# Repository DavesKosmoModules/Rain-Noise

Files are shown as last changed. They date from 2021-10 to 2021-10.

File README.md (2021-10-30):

# Rain-Noise

Rain Photo

25mm Noise Generator

- Noise generator
- White
- Pink
- Red / Brown
- Violet

Contained are schematics & gerber files for pcb fabrication of both electrical and front panel. This is sutiable for entry level however a basic level of electronics, soldering, fault finding, and some basic tools are required.

[Schematic](/Docs/Rain-Schematic.pdf)

[BOM](Docs/Rain-BOM.pdf)

To calibrate, four pots can be accessed through the holes on the front plate. 

 ` ` | ` `
 --| --
` `   | PINK      
WHITE| 
BROWN   | VIOLET

- Adjust the white pot first as this noise if filtered for the remaining sources, looking for an output of +- 5V. 
- Adjust the three remaining pots for the respective output levels. 

If you wish to edit in ki-cad the following dependencies are required

 https://github.com/holmesrichards/Kosmo_panel
 
 https://github.com/holmesrichards/aoKicad

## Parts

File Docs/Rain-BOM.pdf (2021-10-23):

Id | Designator | Package | Quantity | Designation
| 1 J2,J1,J3,J5 | Jack_6.35mm_PJ_629HAN | | 4 AudioJack2_SwitchT
2 C1,C3,C4,C10 C_Disc_D3.0mm_W1.6mm_P2.50mm | 4 1uF
| 3 c1,C17,C18 | CP_Radial_D6.3mm_P2.50mm | | 3 10uF
| 4 C2 | C_Disc_D3.0mm_W1.6mm_P2.50mm | | 1 3.3nF
| 5 C5 | C_Disc_D3.0mm_W1.6mm_P2.50mm | | 1 220nF
| 6 C6,C7,C8 | C_Disc_D3.0mm_W1.6mm_P2.50mm | | 3 47nF
| 7 C9 | C_Disc_D3.0mm_W1.6mm_P2.50mm | | 1 33nF

8

| C21,C22,C23,C
| 24 | C_Disc_D3.0mm_W1.6mm_P2.50mm | | 4 0.1uF
| 9 D1,D2 | D_DO‐41_SOD81_P10.16mm_Horizontal | | 2 1N5817
| 10 J6 | Power_Header | | 1 Synth_power_2x5_passive
| 11 Q1 | TO‐92_Inline_Wide | | 1 2N3904
| 12 R1,R2,R8 | R_Axial_DIN0207_L6.3mm_D2.5mm_P10.16mm_Horizontal | | 3 470k
| 13 R3 | R_Axial_DIN0207_L6.3mm_D2.5mm_P10.16mm_Horizontal | | 1 6k8

14

R4,R6,R9,R12,R
13,R14,R15,R1
6 | R_Axial_DIN0207_L6.3mm_D2.5mm_P10.16mm_Horizontal | 8 10k
15 R5 | R_Axial_DIN0207_L6.3mm_D2.5mm_P10.16mm_Horizontal | 1 3k

16

R7,R22,R23,R2
4,R26 | R_Axial_DIN0207_L6.3mm_D2.5mm_P10.16mm_Horizontal | 5 1k
17 R10 | R_Axial_DIN0207_L6.3mm_D2.5mm_P10.16mm_Horizontal | 1 300
18 R11 | R_Axial_DIN0207_L6.3mm_D2.5mm_P10.16mm_Horizontal | 1 2.2M

19

RV1,RV2,RV3,R
V4 | Potentiometer_Bourns_3296W_Vertical_screw_centered | 4 1M
20 U1,U2 | DIP‐14_W7.62mm_Socket_LongPads | 2 TL074

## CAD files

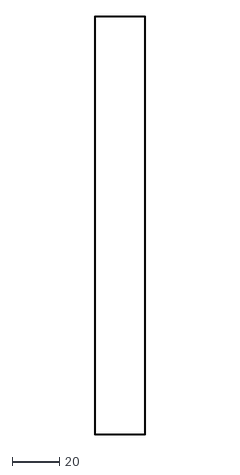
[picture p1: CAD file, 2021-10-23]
dxf/Kosmo Noise-Edge_Cuts.dxf
21.2 x 176.2

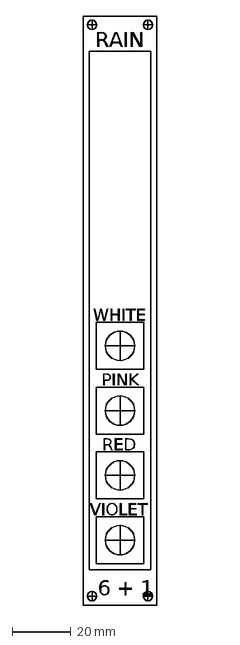
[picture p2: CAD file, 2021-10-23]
NoisePlatesExport.dxf
6 + 1
RAIN
PINK
WHITE
RED
VIOLET

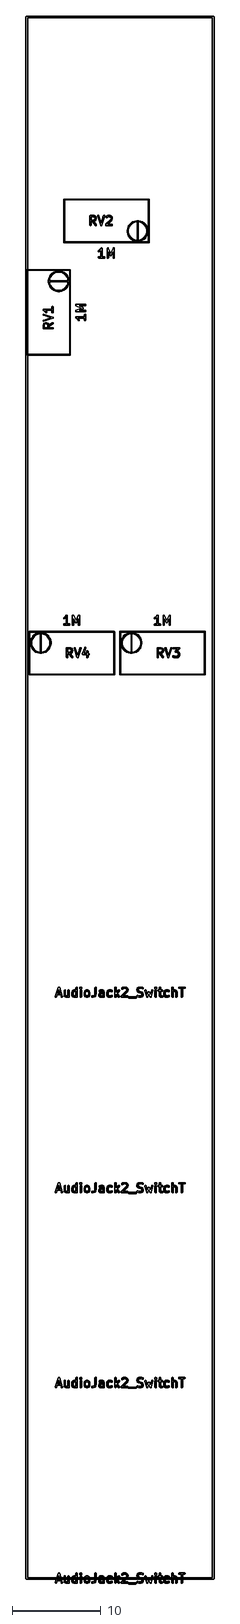
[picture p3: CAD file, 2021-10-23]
dxf/Kosmo Noise-F_Fab.dxf
21.2 x 176.7

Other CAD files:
Noise Faceplates.dwg
NoisePlatesExport.dwg
dxf/Kosmo Noise-F_SilkS.dxf

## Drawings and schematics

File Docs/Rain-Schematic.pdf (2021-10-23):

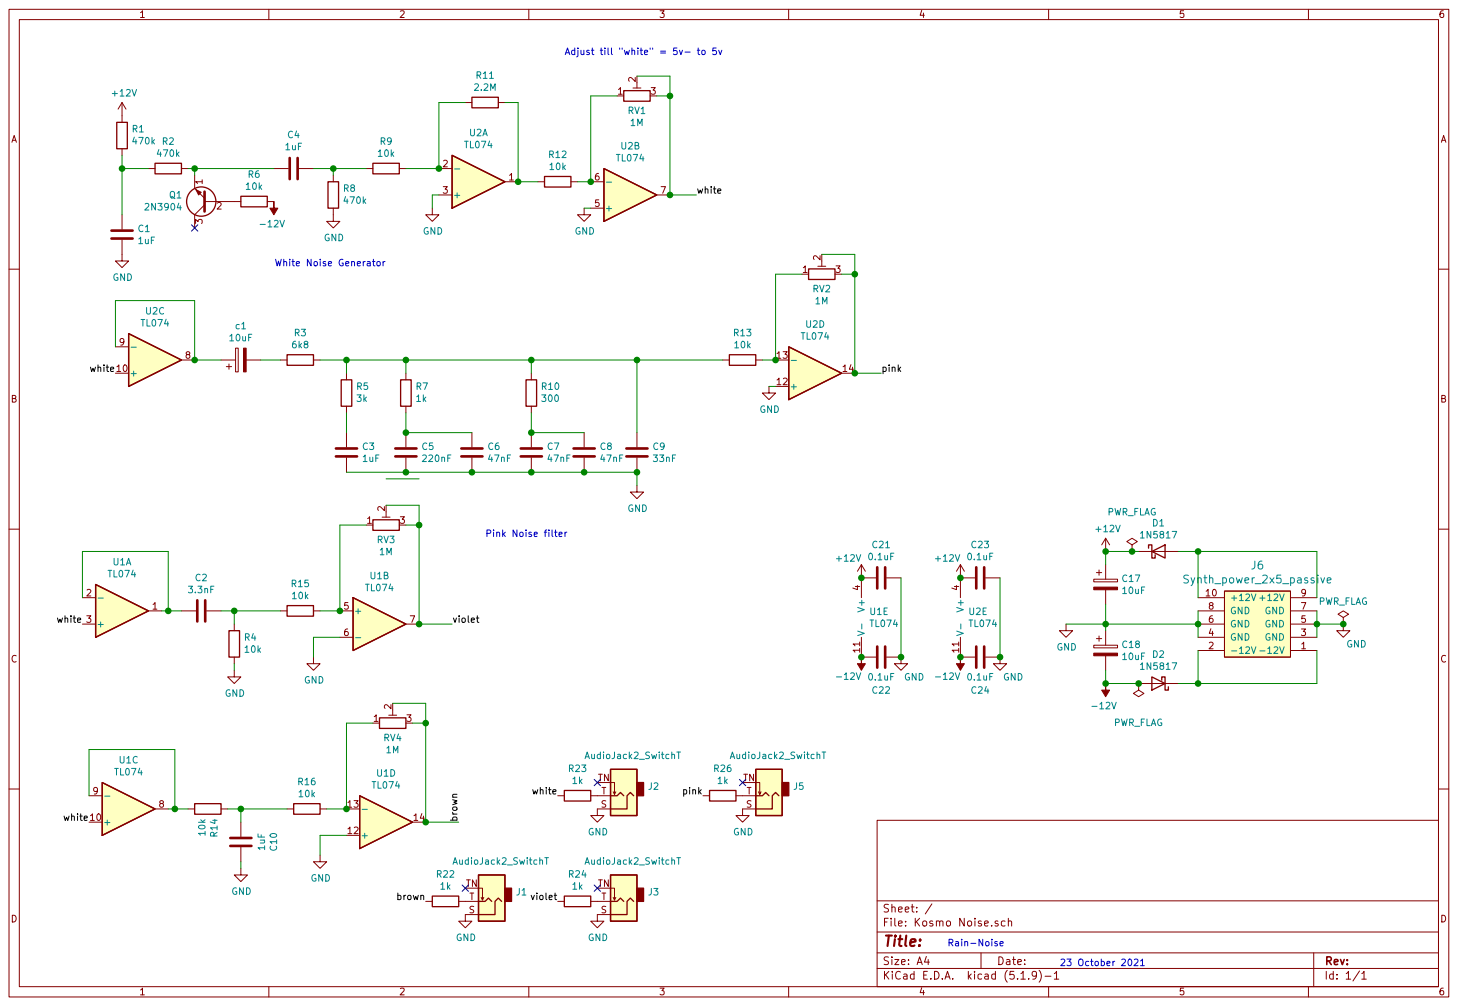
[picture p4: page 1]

Adjust till "white" = 5v- to 5v Pink Noise filter

pink White Noise Generator
47nF GND

Id: 1/1 Title: File: Kosmo Noise.sch Sheet: /

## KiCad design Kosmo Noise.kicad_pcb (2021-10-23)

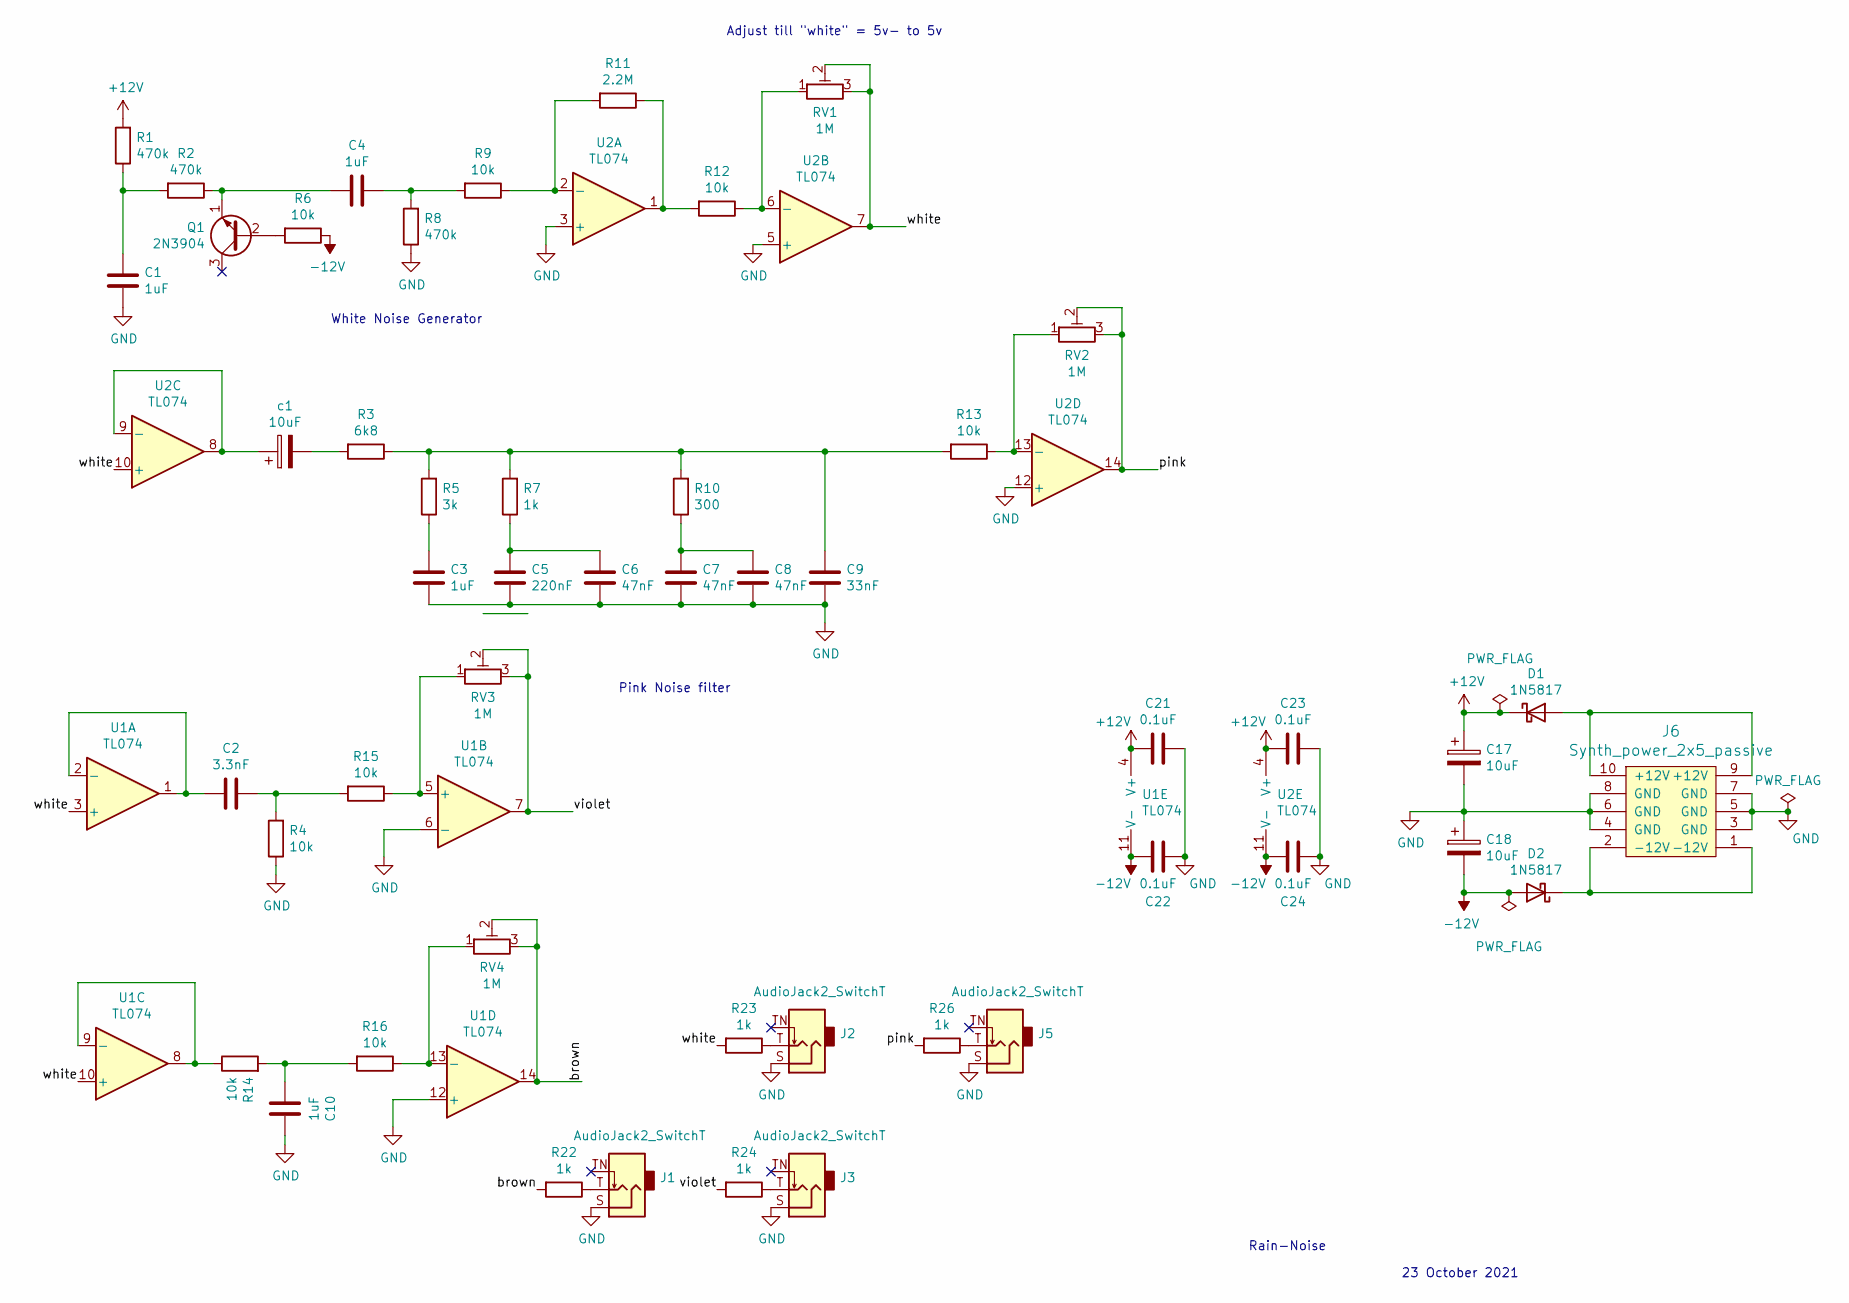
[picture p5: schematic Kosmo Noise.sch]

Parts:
C1, C3, C4, C10: 1uF; C_Disc_D3.0mm_W1.6mm_P2.50mm
C2: 3.3nF; C_Disc_D3.0mm_W1.6mm_P2.50mm
C5: 220nF; C_Disc_D3.0mm_W1.6mm_P2.50mm
C6, C7, C8: 47nF; C_Disc_D3.0mm_W1.6mm_P2.50mm
C9: 33nF; C_Disc_D3.0mm_W1.6mm_P2.50mm
C17, C18: 10uF; CP_Radial_D6.3mm_P2.50mm
C21, C22, C23, C24: 0.1uF; C_Disc_D3.0mm_W1.6mm_P2.50mm
D1, D2: 1N5817; D_DO-41_SOD81_P10.16mm_Horizontal
J1, J2, J3, J5: AudioJack2_SwitchT; Jack_6.35mm_PJ_629HAN
J6: Synth_power_2x5_passive; Power_Header
Q1: 2N3904; TO-92_Inline_Wide
R1, R2, R8: 470k; R_Axial_DIN0207_L6.3mm_D2.5mm_P10.16mm_Horizontal
R3: 6k8; R_Axial_DIN0207_L6.3mm_D2.5mm_P10.16mm_Horizontal
R4, R6, R9, R12, R13, R14, R15, R16: 10k; R_Axial_DIN0207_L6.3mm_D2.5mm_P10.16mm_Horizontal
R5: 3k; R_Axial_DIN0207_L6.3mm_D2.5mm_P10.16mm_Horizontal
R7, R22, R23, R24, R26: 1k; R_Axial_DIN0207_L6.3mm_D2.5mm_P10.16mm_Horizontal
R10: 300; R_Axial_DIN0207_L6.3mm_D2.5mm_P10.16mm_Horizontal
R11: 2.2M; R_Axial_DIN0207_L6.3mm_D2.5mm_P10.16mm_Horizontal
RV1, RV2, RV3, RV4: 1M; Potentiometer_Bourns_3296W_Vertical_screw_centered
U1, U2: TL074; DIP-14_W7.62mm_Socket_LongPads
c1: 10uF; CP_Radial_D6.3mm_P2.50mm

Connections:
+12V: C17.1, C21.2, C23.2, D1.1 (K), R1.2, U1.4 (V+), U2.4 (V+)
-12V: C18.2, C22.2, C24.2, D2.2 (A), R6.1, U1.11 (V-), U2.11 (V-)
/brown: R22.2, RV4.2, RV4.3, U1.14
/pink: R26.2, RV2.2, RV2.3, U2.14
/violet: R24.2, RV3.2, RV3.3, U1.7
/white: R23.2, RV1.2, RV1.3, U1.3 (+), U1.10 (+), U2.7, U2.10 (+)
GND: C1.2, C3.2, C5.2, C6.2, C7.2, C8.2, C9.2, C10.1, C17.2, C18.1, C21.1, C22.1, C23.1, C24.1, J1.S, J2.S, J3.S, J5.S, J6.3 (GND), J6.4 (GND), J6.5 (GND), J6.6 (GND), J6.7 (GND), J6.8 (GND), R4.1, R8.1, U1.6 (-), U1.12 (+), U2.3 (+), U2.5 (+), U2.12 (+)
unnamed: C1.1, R1.1, R2.2
unnamed: C2.1, R4.2, R15.2
unnamed: C2.2, U1.1, U1.2 (-)
unnamed: C3.1, R5.1
unnamed: C4.1, Q1.1 (E), R2.1
unnamed: C4.2, R8.2, R9.2
unnamed: C5.1, C6.1, R7.1
unnamed: C7.1, C8.1, R10.1
unnamed: C9.1, R3.1, R5.2, R7.2, R10.2, R13.2
unnamed: C10.2, R14.2, R16.2
unnamed: D1.2 (A), J6.9 (+12V), J6.10 (+12V)
unnamed: D2.1 (K), J6.1 (-12V), J6.2 (-12V)
unnamed: J1.T, R22.1
unnamed: J2.T, R23.1
unnamed: J3.T, R24.1
unnamed: J5.T, R26.1
unnamed: Q1.2 (B), R6.2
unnamed: R3.2, c1.2
unnamed: R11.1, R12.2, U2.1
unnamed: R9.1, R11.2, U2.2 (-)
unnamed: R12.1, RV1.1, U2.6 (-)
unnamed: R13.1, RV2.1, U2.13 (-)
unnamed: R14.1, U1.8, U1.9 (-)
unnamed: R15.1, RV3.1, U1.5 (+)
unnamed: R16.1, RV4.1, U1.13 (-)
unnamed: U2.8, U2.9 (-), c1.1

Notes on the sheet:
Adjust till "white" = 5v- to 5v
White Noise Generator
Pink Noise filter
Rain-Noise
23 October 2021

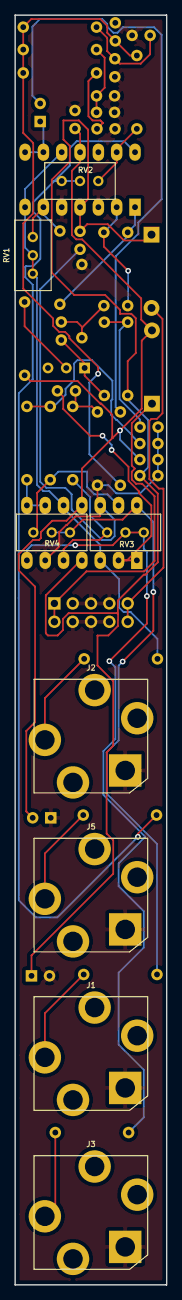
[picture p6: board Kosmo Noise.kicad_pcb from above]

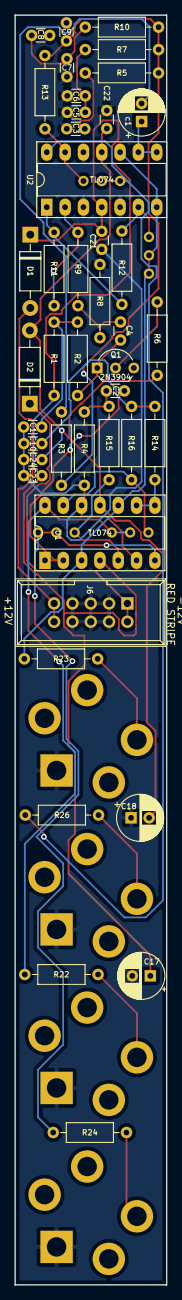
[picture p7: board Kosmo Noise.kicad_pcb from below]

Board: 2 copper layers, 21.0 x 176.0 mm, 51 parts (43 on the bottom side), 33 nets.
